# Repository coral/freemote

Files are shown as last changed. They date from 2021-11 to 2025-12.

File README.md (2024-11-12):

# Freemote - Sony Alpha BLE Remote implemented on the NRF52840

### [Watch the build on Youtube](https://www.youtube.com/watch?v=G_nyD2bTs7A)

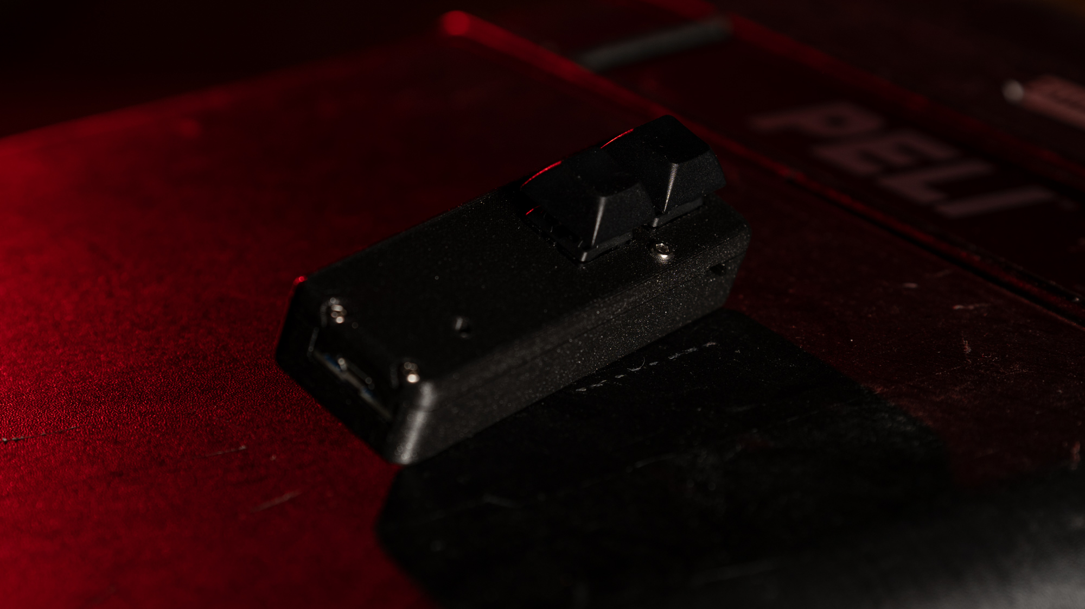
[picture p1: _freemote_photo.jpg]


This is a BLE implementation for the NRF52840 that acts like a BLE (Bluetooth Low Energy) remote for the Sony Alpha series that support the BLE remotes similar to [JJC-RMT-P1BT](https://www.amazon.com/JJC-RMT-P1BT-Bluetooth-Wireless-Commander/dp/B08CR1QPKQ). I've tried this on a Sony A7 III but from my understanding it should work with ZV-1, RX100VII, ZV-E10, A7C, A6100, A6600, A1, A7RIV, A7SIII, A9II, 6400 and A7RIII as well.

Specifically this code runs on the [Adafruit NRF52840 Express](https://www.adafruit.com/product/4062) which costs about $25. The repo is a [PlatformIO](https://platformio.org/) project meaning if you open this it should handle dependencies and the toolchain to program your NRF52840. Currently the code will try to pair with whatever camera is open for pairing (described further down) and save that pairing and then automatically reconnect to that camera when avaliable. There is prob better ways of solving this but yeah, took the easy route here.

## Sony Alpha BLE Remote Protocol

When trying to discover the camera, you have to specifically scan for the "manufacturer data" as Sony uses this to indicate state etc for the camera. So for example an advertistment header might look like this: `0x2D, 0x01, 0x03, 0x00, 0x64, 0x00, 0x45, 0x31, 0x22, 0xEF, 0x00`. Decoding this you get:

| Code | Meaning |
|---|---|
| 2d 01 | Sony Corporation Company Identifier (0x012D) |
| 03 00 | Camera |
| 64 | Protocol Version |
| 00 | ??? |
| 45 31 | Model Code |
| 22 EF 00 | \<tag> CODE \</tag> |

The interesting part here is `0x22 0xEF 0x00` which indicates that the camera is open to pairing. If the camera is not in pairing mode you will get `0x22 0xAF 0x00` instead.

### Remote Control Service

We are specifically interested in consuming the `8000FF00-FF00-FFFF-FFFF-FFFFFFFFFFFF` service which contains two characteristics. 

#### Codes from remote (RemoteCommand 0xFF01)

This is what I initially thought and reflected in the variable names in the code:

| Code | Description |
|---|---|
| 0x0106 | Shutter released |
| 0x0107 | Transitioning to focus |
| 0x0108 | Focus held |
| 0x0109 | Shutter fully pressed  |

However, [Greg Leeds did a better job](https://gregleeds.com/reverse-engineering-sony-camera-bluetooth/) reversing this. With [additional testing script done](./protocol/ble-test.py) by [tao-j](https://github.com/tao-j), the best guesstimate of the command code is summarized in the following table. 

| Code | Description | 
| --- | --- |
| 0x0106 | Shutter Half Up | 
| 0x0107 | Shutter Half Down | 
| 0x0108 | Shutter Fully Up  | 
| 0x0109 | Shutter Fully Down| 
| 0x010e | Record Up | 
| 0x010f | Record Down  | 
| 0x0114 | AF-On Up | 
| 0x0115 | AF-On Down  | 
| 0x0120 | C1 Up | 
| 0x0121 | C1 Down | 
| 0x0244[00~0f] | Zoom Tele Release | 
| 0x0245[10~8f] | Zoom Tele Press | 
| 0x0246[00~0f] | Zoom Wide Release | 
| 0x0247[10~8f] | Zoom Wide Press | 
| 0x026a[00~0f] | Focus In Release  | 
| 0x026b[00~7f] | Focus In Press | 
| 0x026c[00~0f] | Focus Out Release  | 
| 0x026d[00~7f] | Focus Out Press | 

In summary, those codes discovered so far have a length of either 2 or 3 bytes of the format:
```
+-----------------+-----------------+----------------------+
|     Length      |     Command     | Step size (optional) |
+-----------------+-----------------+----------------------+

```

The first byte `Length` is always present, it denotes how many bytes proceeding it: `0x01` for 1 byte, and `0x02` for two bytes. 
The second byte `Command` is the actual command, it either simulates a button or indicates a property change like zoom or focus.
The third byte `Step size` is optional, which is usually accompanied by a property change second byte to denote a step size. Known valid step sizes are listed in the bracket for each command, there could be more, only Sony engineering know that so far. 

Sadly, an exhaustive scan for `Command` codes from `0x00` to `0xff` revealed no extra hidden code.

For button codes, it's of best practice to issue them in pairs of `Down` and `Up`.
The shutter button commands must go through the sequence of "Half down -> Fully down -> Half up -> Fully up", otherwise the camera will be stuck in an inoperable state.

#### Answers from camera (RemoteCommand 0xFF02)

| Code | Meaning |
|---|---|
| **Focus** | |
| 0x02 3F 00 | Lost |
| 0x02 3F 20 | Acquired |
| | |
| **Shutter** | |
| 0x02 A0 00 | Ready |
| 0x02 A0 20 | Shutter active |
| | |
| **Recording** | |
| 0x02 D5 00 | Recording stopped |
| 0x02 D5 20 | Recording started |

### Acknowledgments & Thanks

- [Greg Leeds](https://gregleeds.com/reverse-engineering-sony-camera-bluetooth/)
- [tao-j](https://github.com/tao-j) for further digging, reproing and discovering
- [Violin9906](https://github.com/Violin9906) for testing the electrical optical zoom codes and clarifying some missing details

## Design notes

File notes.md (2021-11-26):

## Remote to camera (0xFF01)
0x0106 let go

0x0107 focus

0x0108 button goes down

0x0109 release button to middle

## Camera back to device (0xFF02)

#### 3F focus

0x02 3F 00 == ready
0x02 3F 20 == Focus acquired 

#### A0 Picture

0x02 A0 20 == Picture taken
0x02 A0 0 == Back from picture, ready

#### D5 Recording

0x02 D5 0 == Recording stopped
0x02 D5 20 == Recording started

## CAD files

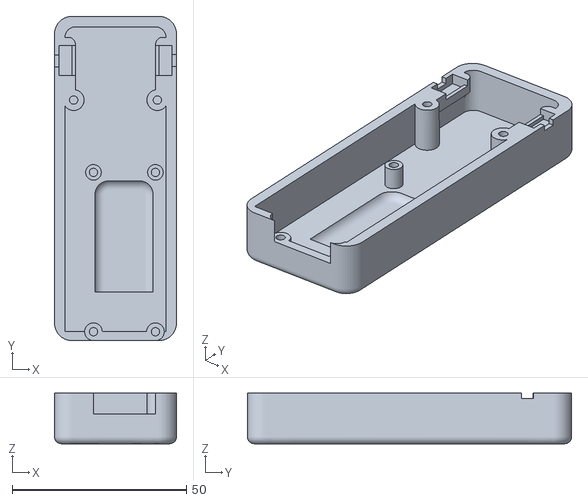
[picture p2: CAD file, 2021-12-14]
3dmodels/freemote-base.stl
35.0 x 93.0 x 14.5

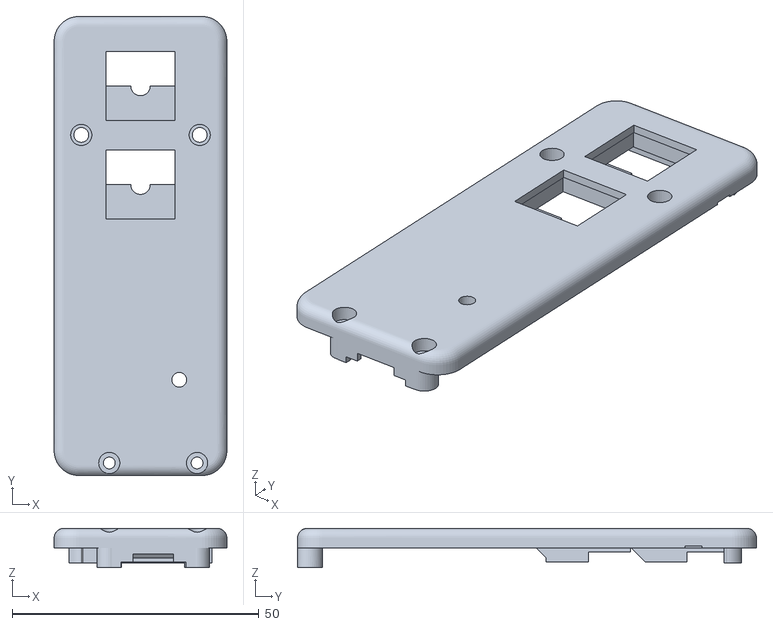
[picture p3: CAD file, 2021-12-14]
3dmodels/freemote-lid.stl
35.0 x 93.0 x 8.00

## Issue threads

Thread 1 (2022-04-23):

Can We check Pairing Status

rohitsangwan01, 2022-04-23:
Hey , nice work ,
After Sending Pair request to camera , is there any way to detect if users accepts that pairing request in camera , or canceled that
or in case if we want to check the pairing status with camera . ( i know we can check if camera if in Pairing mode , or enabled from manufacturer data )

coral, 2022-04-25:
@rohitsangwan01

The TAG data is a bitmask.

PairingSupported | 0x80
PairingEnabled | 0x40
LocationFunctionSupported | 0x20
LocationFunctionEnabled | 0x10
UnknownFunctionSupported | 0x08
UnknownFunctionEnabled | 0x04
RemoteFunctionEnabled | 0x02
Unknown | 0x01

this means you can use the 0x22 tag, bitmask using these to figure out what state the camera is in. If the camera advertises 0x40 it's open for pairing.

https://github.com/coral/freemote/blob/933b97d4dce69a1c5ab54421bcfebb6b438b2546/src/BLECamera.cpp#L229

You can see how I use it here.

rohitsangwan01, 2022-04-25:
@coral yes but this tag data can only tell us if camera is pairable or not , but after connecting camera will not advertise

so first i am connecting to camera
and then sending Pairing command

and pair dialog popup in camera
but this is just one time process

now what i want to check is , if that camera is already paired with my device

either we need to getBonded devices list from platform ,

but is there any way to confirm it from camera programatically

coral, 2022-04-25:
@rohitsangwan01 no you just connect and listen, if the camera starts spamming you updates on the ble services you can assume that it's bonded otherwise it never sends anything.

at least that's how I remembered it.

If you want to know what devices the NRF527840 device has bound to you can use LittleFS and just explore the saved keys and compare MAC addresses but I never got that far since this worked.

rohitsangwan01, 2022-04-25:
@coral ok great , thank you

Closed 2022-04-27.

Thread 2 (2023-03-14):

Focusing

ispybadguys, 2023-03-14:
Is it possible to control the focus in manual focus mode by stepping in or out? I have seen some information on this at https://gregleeds.com/reverse-engineering-sony-camera-bluetooth/. I tried using the Nordic App on Android.

Thanks

Kurt

coral, 2023-03-14:
@ispybadguys probably? never tried it. feel free to run the code and try

ClaesClaes, 2023-03-16:
I have not tried but it's possible. There's an iPhone app called 'sMote - for Sony cameras' on App Store doing exactly this. Adjusting focus via BLE.

ispybadguys, 2023-03-17:
Maybe you know something that I don't. (this is almost certain). I discovered a small error in Greg's commands. The Focus Near consists of a Focus Near Button Down command 0x02 0x6b 0x20 followed by a Focus Near Button Up command 0x02 0x6a 0x00. These commands are 3 bytes long. I tested the commands using Nordic's Android App and it works if I send these as a byte array but the Adafruit library doesn't support this. I tried writing it using 6 each .write8_resp() but the camera doesn't respond. I also tried 6 each .write8() with no joy. Any ideas?

Thanks

Kurt

ispybadguys, 2023-03-17:
Ha! I solved it. I found that there is a .write_resp(char array, len) method. Now it is working

Closed 2023-11-10.

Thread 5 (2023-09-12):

Focus distance information?

jadware, 2023-09-12:
Do you know if it's possible to get the current focal distance, aperture, etc info from the camera?  Given we can step the focus and zoom by sending commands, one would presume this information may be available.  It does appear to be available in the Sony Wi-Fi protocol.

coral, 2023-09-14:
@jadware

Bluetooth Remote protocol does not expose it.

There is an undocumented protocol which Sony has never shipped a product for that is theorized to act as a bridge towards the same parameters as the wifi protocol but yeah it's... undocumented and noone knows :D

Closed 2023-09-14.

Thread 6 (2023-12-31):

Not releasing in bulb mode

shsmad, 2023-12-31:
Hi, I've found, that «Half down -> Fully down -> Half up -> Fully up» works only when shutter speed is fixed. When I set shutter speed to BULB on ILCE-7C (for example, to control timings programmatically), something weird is happening:

1. I send «Half down -> Fully down», shutter is pressed in camera
2. I wait for some time while image is well exposed
3. I send «Half up -> Fully up» supposing it should release the shutter

But the shutter isn't released, the camera doesn't respond at all to «Half up -> Fully up». I was able to release the shutter only with sending «Half down -> Fully down» **second** time (in manual focus mode one can only send just «Fully down» both times).

What's even stranger is that remote controls work the same way: if you press and hold the button in BULB mode, the shutter will not release after you release the button on RC, but it will release after you press it again. Tested on aodelan rmt-p1bta and JJC RMT-P1BT.

Violin9906, 2024-11-12:
Yes, the BLE protocol works more like a Time shutter than a Bulb shutter. You need to send a press and up at both the beginning and end of exposure.

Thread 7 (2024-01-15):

multiple remotes

eried, 2024-01-15:
Hi! thanks for the code! I havent tested this but I wonder if is possible to pair multiple controllers to the camera? I guess you did this a lot while testing (I want to port this to an esp32)

coral, 2024-01-16:
I did a lot of testing but that was 2 years ago so honestly don't remember, maybe? I think the camera remembers a set of devices when you pair.

eried, 2024-01-17:
oh ok

Closed 2024-01-17.

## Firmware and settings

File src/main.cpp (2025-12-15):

#include <Arduino.h>
#include "BLECamera.h"
#include "BLEHandler.h"
#include "RemoteStatus.h"
#include "InputHandler.h"

BLECamera camera;
BLEHandler handler;

void resetTest(void) {
    Serial.println("Clearing bonds");
    handler.clearBonds();
}

void setup()
{
    // Setup the red LED
    pinMode(PIN_LED1, OUTPUT);

    // Configure the Neopixel Status LED
    RemoteStatus *rs = RemoteStatus::access();
    rs->set(Status::BOOT);

    // Setup button handling
    Input::Init(&camera);

    Input::registerResetCallback(resetTest);

// Debug nation bro
#if CFG_DEBUG
    Serial.begin(115200);
    rs->set(Status::WAIT_FOR_SERIAL);
    while (!Serial)
        delay(10);
#endif

    // Initialze BLE
    if (!handler.InitBLE(&camera))
    {
        rs->set(Status::ERROR);
    }
}

void loop()
{
    // Netflix & Chill
    yield();

    // Check for button presses
    Input::process(millis());
}

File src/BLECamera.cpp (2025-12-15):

#include "BLECamera.h"
#include "bluefruit.h"

BLECamera::BLECamera(void)
    : BLEClientService("8000FF00-FF00-FFFF-FFFF-FFFFFFFFFFFF"),
      _remoteCommand(0xFF01),
      _remoteNotify(0xFF02),
      _shutterStatus(0),
      _focusStatus(0),
      _recordingStatus(0),
      _focusHeld(false)
{
    rs = RemoteStatus::access();
}

void camera_notify_cb(BLEClientCharacteristic *chr, uint8_t *data, uint16_t len)
{
    BLECamera &svc = (BLECamera &)chr->parentService();
    svc._handle_camera_notification(data, len);
}

bool BLECamera::begin(void)
{
    // Invoke base class begin()
    VERIFY(BLEClientService::begin());

    _remoteCommand.begin(this);

    _remoteNotify.setNotifyCallback(camera_notify_cb);
    _remoteNotify.begin(this);

    return true;
}

bool BLECamera::discover(uint16_t conn_handle)
{
    // Call Base class discover
    VERIFY(BLEClientService::discover(conn_handle));

    _conn_hdl = BLE_CONN_HANDLE_INVALID; // make as invalid until we found all chars

    // // Discover all characteristics
    Bluefruit.Discovery.discoverCharacteristic(conn_handle, _remoteCommand, _remoteNotify);

    VERIFY(_remoteCommand.discovered() && _remoteNotify.discovered());

    _conn_hdl = conn_handle;

    return true;
}

void BLECamera::_handle_camera_notification(uint8_t *data, uint16_t len)
{

#if CFG_DEBUG
    Serial.println("Camera data: ");
    Serial.print("LEN: ");
    Serial.print(len);
    Serial.print(" DATA: ");
    for (int n = 0; n < len; n++)
    {
        Serial.print(" ");
        Serial.print(data[n], HEX);
        Serial.print(" ");
    }
    Serial.write("\0\n");
    Serial.flush();
#endif

    if (len == 3)
    {
        if (data[0] == 0x02)
        {
            switch (data[1])
            {
            case 0x3F:
                _focusStatus = data[2];

                if (_focusStatus == 0x20)
                {
                    rs->set(Status::FOCUS_ACQUIRED);
                }
                else
                {
                    rs->set(Status::READY);
                }

                break;

            case 0xA0:
                _shutterStatus = data[2];

                if (_shutterStatus == 0x20)
                {
                    rs->set(Status::SHUTTER);
                }
                else
                {
                    rs->set(Status::READY);
                }

                break;

            case 0xD5:
                _recordingStatus = data[2];
                break;
            }
        }
    }
}

bool BLECamera::enableNotify(void)
{
    return _remoteNotify.enableNotify();
}

bool BLECamera::disableNotify(void)
{
    return _remoteNotify.disableNotify();
}

bool BLECamera::pressTrigger(void)
{
    // Timeout for focus and shutter operations
    uint32_t startTime = millis();

    if (!_focusHeld)
    {
        // Reset focus status
        _focusStatus = 0x00;

        // Focus
        _remoteCommand.write16_resp(PRESS_TO_FOCUS);

        if (mode == AUTO_FOCUS)
        {
            // Wait for focus acquisition (with timeout)
            while (_focusStatus != 0x20)
            {
                yield();

                if ((millis() - startTime) >= 3000)
                {
                    break;
                }
            }
        }
    }

    // Release back to focus
    _remoteCommand.write16_resp(HOLD_FOCUS);

    // Reset shutter status
    _shutterStatus = 0x00;

    // Shutter
    _remoteCommand.write16_resp(TAKE_PICTURE);

    if (mode == AUTO_FOCUS)
    {
        // Wait for shutter completion (with timeout)
        while (_shutterStatus != 0x20)
        {
            yield();

            if ((millis() - startTime) >= 3000)
            {
                break;
            }
        }
    }

    return true;
}

bool BLECamera::releaseTrigger(void)
{

    // Release back to focus
    _remoteCommand.write16_resp(HOLD_FOCUS);

    delay(10);

    // Let go?
    _remoteCommand.write16_resp(SHUTTER_RELEASED);

    return true;
}


void BLECamera::focus(bool f)
{
    if (mode == AUTO_FOCUS)
    {
        _focusHeld = f;

        if (f)
        {
            // Focus
            _remoteCommand.write16_resp(PRESS_TO_FOCUS);
        }
        else
        {
            _remoteCommand.write16_resp(HOLD_FOCUS);
            delay(10);

            // Let go?
            _remoteCommand.write16_resp(SHUTTER_RELEASED);
        }
    }
}

void BLECamera::release(void)
{
    // Release back to focus
    _remoteCommand.write16_resp(HOLD_FOCUS);

    delay(10);

    // Let go?
    _remoteCommand.write16_resp(SHUTTER_RELEASED);
}

// is_camera returns true if this is a sony cam
bool BLECamera::isCamera(std::array<uint8_t, 16> data)
{
    return std::equal(CAMERA_MANUFACTURER_LOOKUP.begin(), CAMERA_MANUFACTURER_LOOKUP.end(), data.begin());
}

// pairing_status returns true if camera is open for pairing, false otherwise
bool BLECamera::pairingStatus(std::array<uint8_t, 16> data)
{

    // We are certain this is a camera, lets check for pairing status
    auto it = std::find(data.begin(), data.end(), 0x22);
    if (it != data.end() && (it + 1) != data.end())
    {
        // Bitmasks:
        //
        // PairingSupported	0x80
        // PairingEnabled	0x40
        // LocationFunctionSupported	0x20
        // LocationFunctionEnabled	0x10
        // UnknownFunctionSupported	0x08
        // UnknownFunctionEnabled	0x04
        // RemoteFunctionEnabled	0x02
        // Unknown	0x01

        if ((*(it + 1) & 0x40) == 0x40 && (*(it + 1) & 0x02) == 0x02)
        {
            // Camera is ready to pair
            return true;
        }
    }

    // camera does not want to pair
    return false;
}

// This just sends the commands in order to test, doesn't work if the camera struggles to focus.
// bool BLECamera::_ignorantTrigger(void)
// {

//     // Focus
//     _remoteCommand.write16_resp(0x0701);

//     // Shutter
//     _remoteCommand.write16_resp(0x0901);

//     // Release back to focus
//     _remoteCommand.write16_resp(0x0801);

//     // Let go?
//     _remoteCommand.write16_resp(0x0601);

//     return true;
// }

void BLECamera::setMode(Mode m)
{
    _focusHeld = false;
    mode = m;
}

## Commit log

2021-11-26 Camera connections
2021-12-11 updated status led
2021-12-11 switch to FastLED, again
2021-12-14 3d models
    [freemote-base.stl, freemote-lid.stl]
2021-12-15 fix reading switch at startup
    [BLECamera.cpp, InputHandler.h]
2022-02-06 Fixed support for A7 IV + now actually parsing the bitmask instead of being dumb
    [BLECamera.cpp, BLEHandler.cpp]
